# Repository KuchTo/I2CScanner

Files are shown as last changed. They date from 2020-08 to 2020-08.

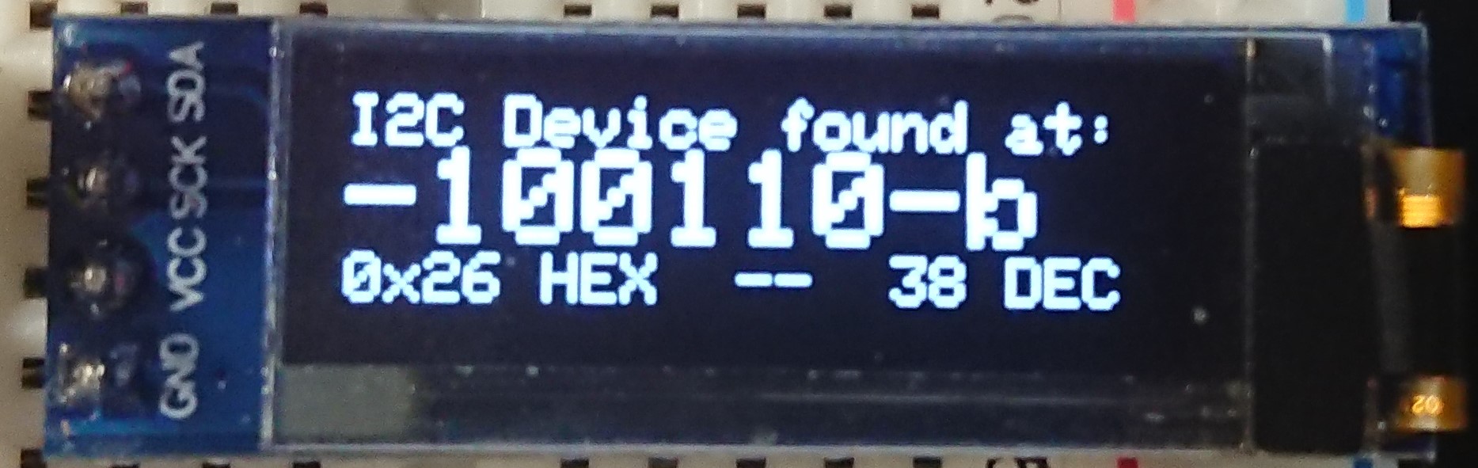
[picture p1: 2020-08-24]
I2C_Scanner_OLed.jpg

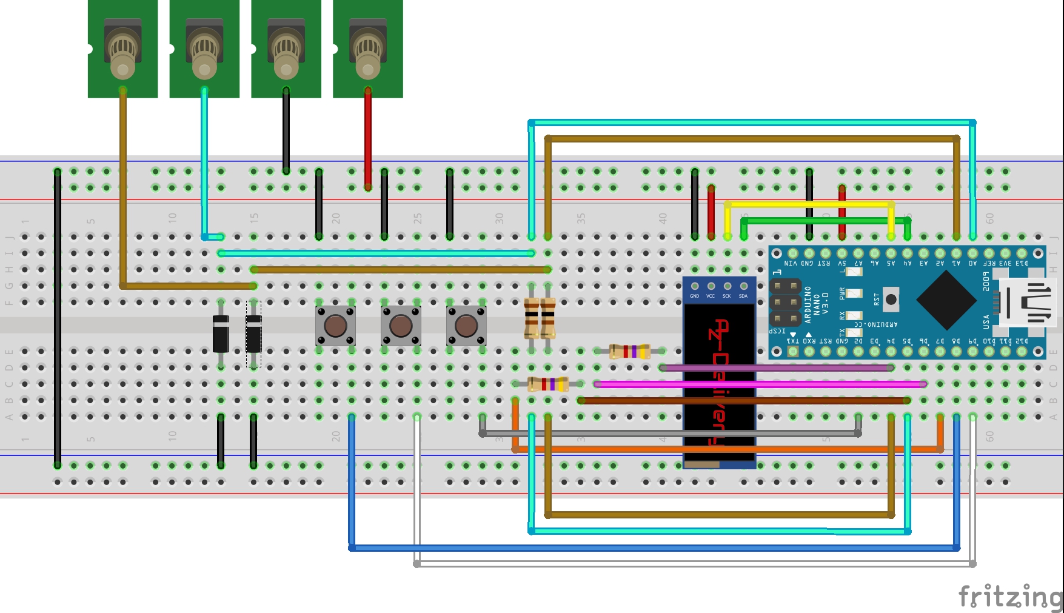
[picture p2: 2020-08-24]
Tool_I2CScanner_Teil_3_Steckplatine.jpg

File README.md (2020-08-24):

# I2CScanner
I2C Mini Scanner mit Frequenzgenerator und Logiktester 
Ein praktischer und kostengünstiger I2C Scanner - Reihe „Multitool“ Teil 1

Hallo und willkommen zu einer neuen Reihe rund um unseren Arduino! In dieser Reihe werden wir uns über insgesamt 3 Teile ein kleines kostengünstiges Elektronik Multitool bauen, das es ermöglicht IC2 Adressen aus einem angeschlossenen I2C Bauteil herauszulesen, (I2C Scanner), eine Rechteckspannung von 5 Volt in variabler Frequenz auszugeben und Spannung im Bereich von 0-5 Volt messen kann. In unserem ersten Teil werden wir einen I2C Scanner bauen. Doch warum schon wieder einen I2C - Scanner? Auslöser war, dass ich für ein anderes Projekt dringend eine Bestimmung der IC2 Adresse eines Bausteines brauchte, jedoch nicht so einfach ein Datenblatt für diesen Baustein im Internet fand. Also musste ein selbstgebauter I2C Scanner her. Auf nun folgenden Suche nach einem kostengünstigen Open Source IC2 Scanner waren die selbstaufgelegten Vorgaben für diesen Scanner die folgenden:

1)	Einfachheit: Kein Anschluss an einen PC benötigt. Für den Betrieb oder das Ablesen der I2C Adressen ist kein PC nötig.

2)	Minimalistisch: So kleine Bauteile wie möglich. (Unterbringung in einem kleinen Gehäuse)

3)	Kosteneffizienz: Keine unnötig teure Hardware. 

4)	Hardwareeffizienz: keine "brachliegenden" Ressourcen der Hardware wie WLAN, Bluetooth etc.

5)	Sparsam: Betrieb mit einem Akkupack möglich.
 
Ein System das alle die o.g. Kriterien für einen IC2 Scanner erfüllt, konnte ich nicht jedoch nicht finden. Also hieß es: Selbst machen und so ist dieser Blog entstanden. Kommen wir zunächst zu einigen Überlegungen:
Das erste Ziel, ohne PC auszukommen, kann nur mit einem eigenen Display erreicht werden, auf dem die Daten direkt angezeigt werden können.

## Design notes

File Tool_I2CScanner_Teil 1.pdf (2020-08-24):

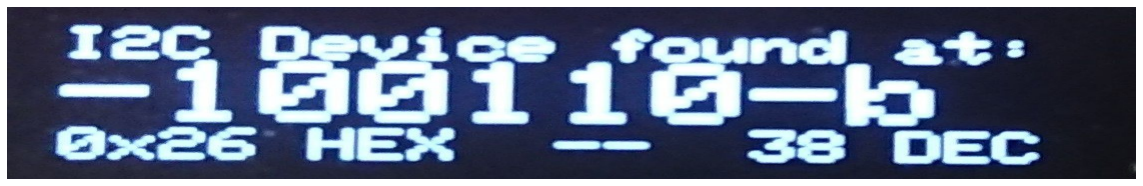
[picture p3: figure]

Ein praktischer und kostengünstiger I2C Scanner - Reihe „Multitool“ Teil 1

Hallo und willkommen zu einer neuen Reihe rund um unseren Arduino! In dieser Reihe werden wir uns über insgesamt 3 Teile ein kleines kostengünstiges Elektronik Multitool bauen, das es ermöglicht IC2 Adressen aus einem angeschlossenen I2C Bauteil herauszulesen, (I2C Scanner), eine Rechteckspannung von 5 Volt in variabler Frequenz auszugeben und Spannung im Bereich von 0-5 Volt messen kann. In unserem ersten Teil werden wir einen I2C Scanner bauen. Doch warum schon wieder einen I2C - Scanner? Auslöser war, dass ich für ein anderes Projekt dringend eine Bestimmung der IC2 Adresse eines Bausteines brauchte, jedoch nicht so einfach ein Datenblatt für diesen Baustein im Internet fand. Also musste ein selbstgebauter I2C Scanner her. Auf nun folgenden Suche nach einem kostengünstigen Open Source IC2 Scanner waren die selbstaufgelegten Vorgaben für diesen Scanner die folgenden:

1) Einfachheit: Kein Anschluss an einen PC benötigt. Für den Betrieb oder das Ablesen der I2C Adressen ist kein PC nötig.
2) Minimalistisch: So kleine Bauteile wie möglich. (Unterbringung in einem kleinen Gehäuse)
3) Kosteneffizienz: Keine unnötig teure Hardware.
4) Hardwareeffizienz: keine "brachliegenden" Ressourcen der Hardware wie WLAN, Bluetooth etc.
5) Sparsam: Betrieb mit einem Akkupack möglich.

Ein System das alle die o.g. Kriterien für einen IC2 Scanner erfüllt, konnte ich nicht jedoch nicht finden. Also hieß es: Selbst machen und so ist dieser Blog entstanden. Kommen wir zunächst zu einigen Überlegungen:
Das erste Ziel, ohne PC auszukommen, kann nur mit einem eigenen Display erreicht werden, auf dem die Daten direkt angezeigt werden können. Durch die Vorgabe eines minimalistischen Designs, auf dem nur so wenig wie möglich Platz zur Verfügung steht, blieb nach Sondierung der Displays auf der AZ-Delivery Seite nur das O-Led 128x64 Pixel in der engeren Auswahl. Dieses Display benötigt aber seinerseits schon einen I2C Bus um zu funktionieren. Was nun? Prozessoren mit 2 parallelen I2C Bussen "on Board" wie sie der ESP32 haben, fielen aber aufgrund der überzogenen Hardware (Bluetooth, WLAN, großer Speicher) für dieses Projekt durch. Ebenso aus gleichem Grunde der ESP8266 (Kosteneffizienz und Hardwareeffizienz).Blieb also nur der Arduino Nano für das Projekt übrig, den wir mit einem kleinen "Trick" auch nutzen können: Wir emulieren per Software einen weiteren I2C Port, der für das Scannen benutzt wird (Im folgenden Software I2C genannt).

Der Hardware I2C Bus wird für die Ansteuerung des O-Led Displays genutzt. Glücklicherweise gibt es bereits eine fertige Bibliothek um einen I2C Bus in Software zu emulieren. Diese heißt „Soft Wire“ und ist von Steve Marple.
Die Bibliothek kann von hier heruntergeladen werden: https://github.com/stevemarple/SoftWire
Weitere Informationen zu dieser Bibliothek finden sich auch auf der Seite https://www.arduinolibraries.info/libraries/soft-wire
Bevor also mit unserem heutigen Projekt begonnen werden kann, muss erst diese Bibliothek in bekannter Weise installiert werden. Für den I2C Scanner aus dem heutigen Blog benötigen Sie darüber hinaus noch folgende Teile aus dem Shop:
Anzahl | Bezeichnung | Anmerkung

### 1 Arduino Nano

1 0,91 Zoll OLED I2C Display 128 x 32 Pixel
2 4,7 KOhm Widerstände

Danach kann die Hardware gemäß folgender Fritzing-Zeichnung aufgebaut werden:

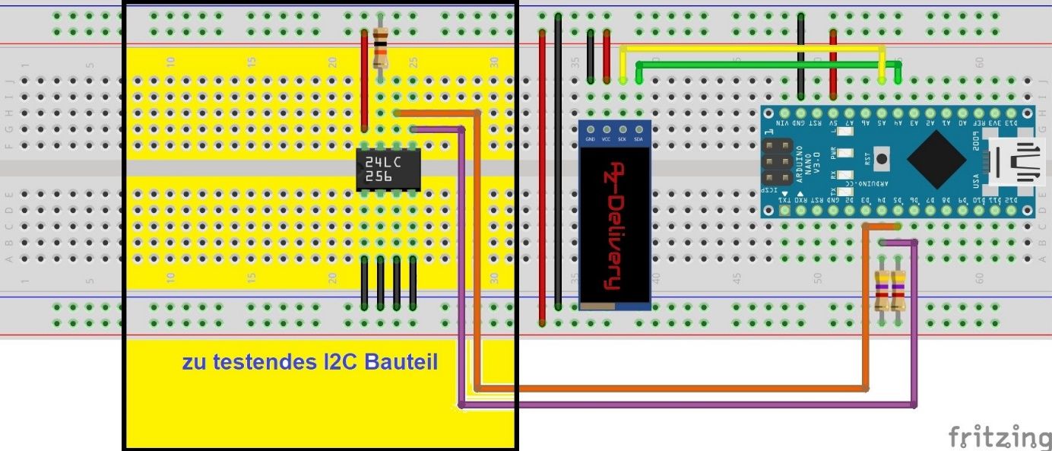
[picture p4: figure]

Beachten Sie die 4,5 K-Ohm Pullup-Widerstände für die Software I2C Schnittstelle. Diese werden für die Funktion benötigt. Aufgebaut auf einem Breadboard und in Betrieb sieht das ganze nun so aus:

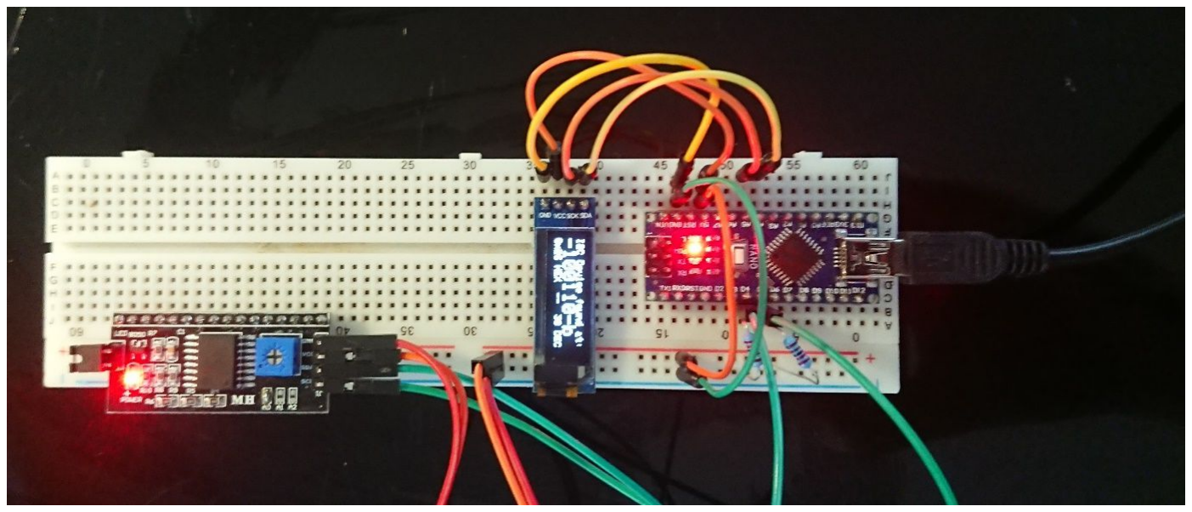
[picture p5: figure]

Nach dem Aufbau kann folgender Code hochgeladen werden:

// Tobias Kuch 2020 GPL 3.0 tobias.kuch@googlemail.com
// https://github.com/kuchto

/*
Dieser kurze Sketch durchsucht den I2C-Bus nach Geräten. Wenn ein Gerät gefunden wird, wird es auf einem 128x64 OLed Display
mit seiner Adresse in den Formaten Binär, Hexadezimal und Dezimal angezeigt.
*/

#include <Wire.h>

#include <SoftWire.h>

#include <AsyncDelay.h>

#include "SSD1306Ascii.h"

#include "SSD1306AsciiWire.h"

#define oLed_I2C_ADDRESS 0x3C #define SoftSDA 4

#define SoftSCL 5

const uint8_t firstAddr = 1; const uint8_t lastAddr = 0x7F;

SSD1306AsciiWire oled;
SoftWire sw(SoftSDA, SoftSCL);

//------------------------------------------------------------------------------

uint8_t I2C_Device_found_at_Address= 0;
uint16_t Round = 0;
bool AlreadyScan = false;

void setup()
{
Wire.begin();

Wire.setClock(400000L);
sw.setTimeout_ms(200); // Set how long we are willing to wait for a device to respond oled.begin(&Adafruit128x32, oLed_I2C_ADDRESS);
oled.setFont(Adafruit5x7);
oled.clear();
oled.set1X();
oled.clear();
oled.setCursor(0, 0);
oled.print("Scanning I2C Bus..."); oled.setCursor(0, 1);
oled.print("Initital Scan.");
}
//------------------------------------------------------------------------------

bool scanI2C()
{
bool detected=false;
for (uint8_t addr = firstAddr; addr <= lastAddr; addr++)
{
delayMicroseconds(50);
uint8_t startResult = sw.llStart((addr << 1) + 1); // Signal a read
sw.stop();
if ((startResult==0) & (I2C_Device_found_at_Address != addr)) // New I2C Device found {
Round = 0;
detected=true;
I2C_Device_found_at_Address = addr; AlreadyScan = false;
oled.set1X();
oled.setCursor(0,0);
// oled.clear();
oled.print("I2C Device found at: "); oled.setCursor(0,1);
oled.set2X();
oled.setCursor(0,1);
oled.print("-");
oled.print(addr,BIN);
oled.print("-b ");
oled.set1X();
oled.setCursor(0,3);
oled.print("0x");
if(addr<16) oled.print("0"); oled.print(addr,HEX);
oled.print(" HEX -- ");
if(addr<10) oled.print("0"); oled.print(addr,DEC);
oled.print(" DEC ");
delay(100);
break;
} // Device Found END
} // Scan Round END

if (!detected)

{
I2C_Device_found_at_Address = 0; Round++;
}
return detected;
} // Function END

void loop()
{
if ((!scanI2C()) && (Round > 2)) {
if (!AlreadyScan)
{
AlreadyScan = true;
oled.clear();
oled.setCursor(0, 0);
oled.print("Scanning I2C Bus..."); }
Round = 0;
I2C_Device_found_at_Address = 0; }
delay(200);
}

Sobald nun ein I2C adressierbarer und funktionsfähiger Baustein an den Port 5 (SCL) und Port 4 (SDA) angeschlossen wird, wird dessen Adresse umgehend im O-Led Display in den verschiedenen Zahlensystemen Binär, Dezimal und Hexadezimal angezeigt. Ich wünsche Ihnen viel Spaß beim Bauen und beim Verwenden des I2CScanners. Alle Projekte und Informationen meiner Blogs finden Sie auch unter https://github.com/kuchto.

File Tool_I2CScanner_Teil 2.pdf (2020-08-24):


### Ein einfacher und kostengünstiger Frequenzgenerator -

### Aus der Reihe „Multitool“ Teil 2

Hallo und willkommen zum zweiten Teil unserer Reihe rund um unser "Mini Tool".

Heute spendieren wir unserem Mini Tool zusätzlich zu der Verbesserung der Verwendung des I2C Scanners eine weitere Funktion: Ein Frequenzgenerator mit einem festen Tastgrad von 0,5 (symmetrischer Puls), einstellbar in einem Frequenzbereich von ca. 200 Hz bis ca. 25 Khz. Die Amplitude beträgt 5 Volt, die Effektivspannung Uev ca. 2.5 Volt. Der Puls steht am Pin 8 des Arduinos gegen Masse (GND) des Arduino Nanos für eigene Anwendungen oder Tests zur Verfügung. Das Einstellen der Frequenz in dem o.g. Bereich an Pin 8 des Arduinos erfolgt durch ein 10 K-Ohm Drehpotentiometer, das an den Analog Eingang A0 des Arduinos angeschlossen ist. Das Umschalten zwischen dem Modus "I2C Busscanner" und "Frequenzgenerator" und zurück, erfolgt durch Drücken des Tasters T1.Als weiteres

"Bonbon" im heutigen Teil erfolgt eine Verbesserung der Funktion des IC2 Scanners.

Beim Anschließen an einen I2C Prüfling muss nun NICHT mehr auf den korrekten Anschluss von den Datenleitungen SDA und SCL geachtet werden. Die Adressermittlung erfolgt jetzt unabhängig der Datenleitungsbeschaltung und wird, wie gewohnt, direkt im Display in den Formaten Binär, Dezimal und Hexadezimal

angezeigt.

### Um die neuen Funktionen implementieren zu können, benötigen wir folgende leicht erweiterteHardware:

Anzahl | Bezeichnung | Anmerkung

### 1 Arduino Nano

1 0,91 Zoll OLED I2C Display 128 x 32 Pixel
2 4,7 KOhm Widerstände
1 10-KOhm Präzisions –Drehpotentiometer

### 1 Taster

### Danach kann die Hardware gemäß folgender Fritzing-Zeichnung Schaltung wie folgt erweitert werden:

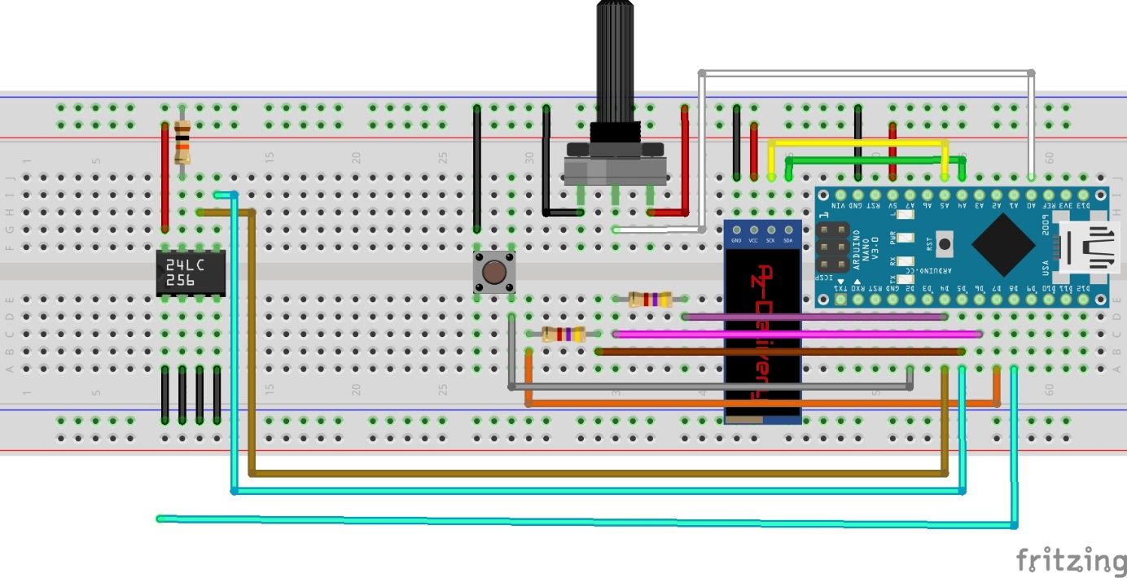
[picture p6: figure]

### Bitte beachten Sie beim Zusammenbau die etwas geänderte Schaltung der beiden

Pullup Widerstände. Diese sind nun nicht mehr direkt an Vcc (5 Volt) angeschlossen, sondern werden ihrerseits auch wieder durch Ports gesteuert. Warum dies Sinn macht, erfahren Sie im nächsten Teil dieser Reihe.

### Bevor es nun an das Hochladen des Codes geht, stellen Sie bitte sicher, dass bereits die Bibliothek „Soft Wire“ von Steve Marple in Ihrer IDE installiert ist. Die Bibliothek kann andernfalls von hier heruntergeladen werden. Weitere Informationen zu dieser

Bibliothek finden sie auch auf dieser Seite.

### Nun kann folgender Code auf den Arduino Nano geladen werden:

// Tobias Kuch 2020 GPL 3.0 tobias.kuch@googlemail.com
// https://github.com/kuchto

/*
Dieser kurze Sketch durchsucht den I2C-Bus nach Geräten. Wenn ein Gerät gefunden wird, wird es auf einem 128x64 OLed Display
mit seiner Adresse in den Formaten Binär, Hexadezimal und Dezimal angezeigt.
*/

#include <Wire.h>

#include <SoftWire.h>

#include <AsyncDelay.h>

#include "SSD1306Ascii.h"

#include "SSD1306AsciiWire.h"

#define oLed_I2C_ADDRESS 0x3C #define SoftI2CA 4

#define SoftI2CB 5

#define POTAConfig 6

#define POTBConfig 7

#define ModeSwitch 2 // Pin Modus Taster #define SQAREWaveOutputPin 8

#define POTENTIOMETER A0

const uint8_t firstAddr = 1; const uint8_t lastAddr = 0x7F;

SSD1306AsciiWire oled;
SoftWire sw(SoftI2CA, SoftI2CB);
SoftWire sw_rev(SoftI2CB, SoftI2CA);

//------------------------------------------------------------------------------

uint8_t I2C_Device_found_at_Address= 0;
uint16_t Round = 0;
bool AlreadyScan = false;
bool Alreadypressed = false;
bool Modeswitched = false;

byte SelectedMode = 0;
int oldvaluea = 0;

ISR(TIMER1_COMPA_vect){ //Timer1 interrupt. Schaltet Pin 8 um.
// Weitere Infos auf: https://www.mikrocontroller.net/articles/AVR-Tutorial:_Timer digitalWrite(SQAREWaveOutputPin,!(digitalRead(SQAREWaveOutputPin)));// Aufruffrequenz maximal: 2.604 Khz
//Frequenz an Pin 8(Hz) = (Arduino clock speed 16,000,000Hz) / (prescaler * (compare match register + 1)) / 2
}

void setup()
{
pinMode(ModeSwitch,INPUT_PULLUP); pinMode(SQAREWaveOutputPin, OUTPUT); pinMode(SoftI2CA, OUTPUT); pinMode(SoftI2CB, OUTPUT); pinMode(POTAConfig, OUTPUT); pinMode(POTBConfig, OUTPUT); digitalWrite (POTAConfig, HIGH); digitalWrite (POTBConfig, HIGH);
Serial.begin(9600);
cli(); | //stoppe alle Interrupts
TCCR1A = 0; | // set entire TCCR1A register to 0 TCCR - Timer/Counter Control
Register
TCCR1B = 0; | // Setze Timer/Counter Control Register TCCR1B auf 0
TCCR1B |= (1 << WGM12); | // Schalte Clear Timer on Compare (CTC) Modus ein
// TCCR1B |= (1 << CS12) | (1 << CS10); // Setze CS10 und CS12 Bit auf 1 für den 1024 Prescaler.
Maximalfrequenz: 7.812 Khz

TCCR1B |= (1 << CS12); | // Setze CS12 Bit auf 1 für den 256 Prescaler.
TCNT1 = 0; | // Initialisiere Zähler/Zeitgeber Register Wert auf 0
OCR1A = 130;// Aufruffrequenz Timer 1 241 Hz * 2
TIMSK1 |= (1 << OCIE1A); // Erlaube Timer compare interrupt TIMSK - Timer/Counter Interrupt Mask Register
sei();//allow interrupts
Wire.begin();
Wire.setClock(400000L);
sw.setTimeout_ms(200); // Set how long we are willing to wait for a device to respond sw_rev.setTimeout_ms(200); // Set how long we are willing to wait for a device to respond oled.begin(&Adafruit128x32, oLed_I2C_ADDRESS);
oled.setFont(Adafruit5x7);
oled.clear();
oled.set1X();
oled.clear();
oled.setCursor(0, 0);
oled.print("Scanning I2C Bus..."); oled.setCursor(0, 1);
oled.print("Initital Scan.");
}
//------------------------------------------------------------------------------

bool scanI2C()
{
bool detected=false;
for (uint8_t addr = firstAddr; addr <= lastAddr; addr++)
{
delayMicroseconds(50);
uint8_t startResult = sw.llStart((addr << 1) + 1); // Signal a read
sw.stop();
if ((startResult==0) & (I2C_Device_found_at_Address != addr)) // New I2C Device found {
Round = 0;
detected=true;
I2C_Device_found_at_Address = addr; AlreadyScan = false;
oled.set1X();
oled.setCursor(0,0);
// oled.clear();
oled.print("I2C Device found at: "); oled.setCursor(0,1);
oled.set2X();
oled.setCursor(0,1);
oled.print("-");
oled.print(addr,BIN);
oled.print("-b ");
oled.set1X();
oled.setCursor(0,3);
oled.print("0x");
if(addr<16) oled.print("0"); oled.print(addr,HEX);
oled.print(" HEX -- ");
if(addr<10) oled.print("0");

oled.print(addr,DEC);
oled.print(" DEC ");
delay(50);
break;
} // Device Found END
} // Scan Round END

if (!detected)
{
I2C_Device_found_at_Address = 0; Round++;
}
return detected;
} // Function END

bool scanI2C_rev()
{
bool detected=false;
for (uint8_t addr = firstAddr; addr <= lastAddr; addr++)
{
delayMicroseconds(50);
uint8_t startResult = sw_rev.llStart((addr << 1) + 1); // Signal a read
sw_rev.stop();
if ((startResult==0) & (I2C_Device_found_at_Address != addr)) // New I2C Device found {
Round = 0;
detected=true;
I2C_Device_found_at_Address = addr; AlreadyScan = false;
oled.set1X();
oled.setCursor(0,0);
// oled.clear();
oled.print("I2C Device found at: "); oled.setCursor(0,1);
oled.set2X();
oled.setCursor(0,1);
oled.print("-");
oled.print(addr,BIN);
oled.print("-b ");
oled.set1X();
oled.setCursor(0,3);
oled.print("0x");
if(addr<16) oled.print("0"); oled.print(addr,HEX);
oled.print(" HEX -- ");
if(addr<10) oled.print("0"); oled.print(addr,DEC);
oled.print(" DEC ");
delay(50);
break;
} // Device Found END
} // Scan Round END

if (!detected)
{
I2C_Device_found_at_Address = 0; Round++;
}
return detected;
} // Function END

void CheckMode()
{
bool PinStatus = digitalRead(ModeSwitch); if ((PinStatus == LOW) && !(Alreadypressed)) {
SelectedMode++;
if (SelectedMode > 1) { SelectedMode = 0; } Serial.print("Mode changed to: "); Serial.println(SelectedMode);
delay(50);
Alreadypressed = true;
Modeswitched = true;
} else if ((PinStatus == HIGH) && (Alreadypressed)) {
Alreadypressed = false;
}
}

void loop()
{
CheckMode();
if (SelectedMode == 0)
{
if (Modeswitched)
{
oled.clear();
}
Modeswitched = false;
if ((!scanI2C()) && (Round > 2)) {
if (!AlreadyScan)
{
AlreadyScan = true;
oled.clear();
oled.setCursor(0, 0);
oled.print("Scanning I2C Bus..."); }
Round = 0;
I2C_Device_found_at_Address = 0; }
if ((!scanI2C_rev()) && (Round > 2)) {
if (!AlreadyScan)
{
AlreadyScan = true;

oled.clear();
oled.setCursor(0, 0);
oled.print("Scanning I2C Bus..."); }
Round = 0;
I2C_Device_found_at_Address = 0; }
delay(50);
}

if (SelectedMode == 1)
{
if (Modeswitched)
{
oled.clear();
oled.setCursor(0, 0);
oled.print("Square Wave Generator"); }
Modeswitched = false;
int Gb = analogRead(POTENTIOMETER); byte valuea = Gb; // map(Gb,0,1023,0,300); if (valuea != oldvaluea)
{
oldvaluea = valuea ;
cli();//stop interrupts
OCR1A = valuea;
if ( TCNT1 > OCR1A )
{
TCNT1 = OCR1A -1;//initialize counter value to 0 }
sei();//allow interrupts
}
}
// END MainLoop
}

Sobald nun ein I2C adressierbarer und funktionsfähiger Baustein beliebig mit seinen Bus Ports an den Port 5 und Port 4 angeschlossen wird, und das Mini Tool im Modus „I2C Scanner“ betrieben wird, wird dessen Adresse umgehend im O-Led Display angezeigt. Der Frequenzgenerator kann für beliebige eigene Anwendungen genutzt werden, Ich wünsche Ihnen viel Spaß beim Bauen und beim Verwenden des kleinen Tools. Alle Projekte und Informationen meiner Blogs finden Sie, wie immer, auch unter

https://github.com/kuchto.

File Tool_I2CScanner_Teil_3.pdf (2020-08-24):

### Ein Voltmeter für die Digitaltechnik (0-5 Volt) – Aus der Reihe „Multitool“ Teil 3

### Willkommen zum dritten und letzten Teil der Reihe „Mini Multitool“ in der die Funktion des Tools um ein 2-Kanal Voltmeter mit einem Messbereich von 0-5 Volt erweitert wird und der noch eingeschränkte Komfort in der Bedienung sowie der Funktionalität des

im zweiten Teil der Reihe eingeführten Rechteck Frequenzgenerators verbessert wird.

Das generierte Frequenzsignal wird nun nicht mehr über einen separaten Pin ausgegeben, sondern kann bei einem Modus Wechsel mit Hilfe der “Mode-Taste“ direkt an den für den I2C Scanner genutzten Pins 4 und 5 abgegriffen werden. Dabei ist das Ausgangssignal an Pin 4 nicht invertiert und an Pin 5 invertiert. Das Potential

zwischen Pin 4 und Pin 5 beträgt im Frequenzgenerator Modus somit konstant 5 Volt.

Die Ausgänge der Pins 4 und 5 wurden mithilfe zweier Widerstände von je 100 Ohm in Reihe und zwei Zener-Dioden mit je 5,1 Volt Durchbruchsspannung gegen kurzzeitige und geringe Überlastung resistenter gemacht. Das Potentiometer zur Frequenz Einstellung ist zugunsten von 2 Tastern zur genaueren und präziseren Einstellung ersetzt worden. Die ausgegebene Frequenz auf der jeweilig eingestellten Stufe (1- 254) im Bereich von 122 Hz bis 15,625 KHz wird nun auf dem O-Led Display angezeigt. Die Genauigkeit der in der O-Led angezeigten Frequenz hängt dabei von dem Systemquarz ab. In dem hier vorgestellten Code wird von einer genauen Systemquarzfrequenz von 16 MHz. ausgegangen. Sollte Ihr Quarz von dieser

Systemquarzfrequenz | abweichen, | so | tragen | sie | bitte | Ihre | ermittelte

### Systemquarzfrequenz in Hz in der Codezeile

### #define CrystalFreq 16000000 // Systemquarzfrequenz des Arduinos

ein bzw. korrigieren diese nach oben oder unten. Für die Genauigkeit des Voltmeters ist zum einen die Ermittlung der genutzten Analog-Digital Referenzspannung wichtig als auch die Genauigkeit des AD Wandlers. Da wir auf den internen AD Wandler des Arduinos nicht direkt Einfluss nehmen können, bleibt nur die Kalibration der Referenzspannung. Bitte messen Sie dazu mit einem genügend genauen Voltmeter die Spannung an dem „URef“ Pins des Arduinos gegen Masse und tragen die gemessene Spannung in die Codezeile
#define UReference 5.0 | // Spannungsreferenz für den Analogwandler

### ein bzw. korrigieren diese. Im Normalfall sollte diese Spannung im Bereich von 4 bis

maximal 5 Volt liegen.

Um die neuen Funktionen und Schutzmaßnahmen implementieren zu können,

### benötigen wir erneut eine leicht abgeänderte Hardware und damit eine veränderte Teileliste:

Anzahl | Bezeichnung | Anmerkung

### 1 Arduino Nano

1 0,91 Zoll OLED I2C Display 128 x 32 Pixel
2 4,7 KOhm Widerstände
2 100 Ohm Widerstände

### 3 Taster 2 Zener-Dioden 5,1 Volt

### Danach kann die Hardware gemäß folgender Fritzing-Zeichnung Schaltung wie folgt erweitert werden:

| Anschluss Ports und 5 Volt Potential

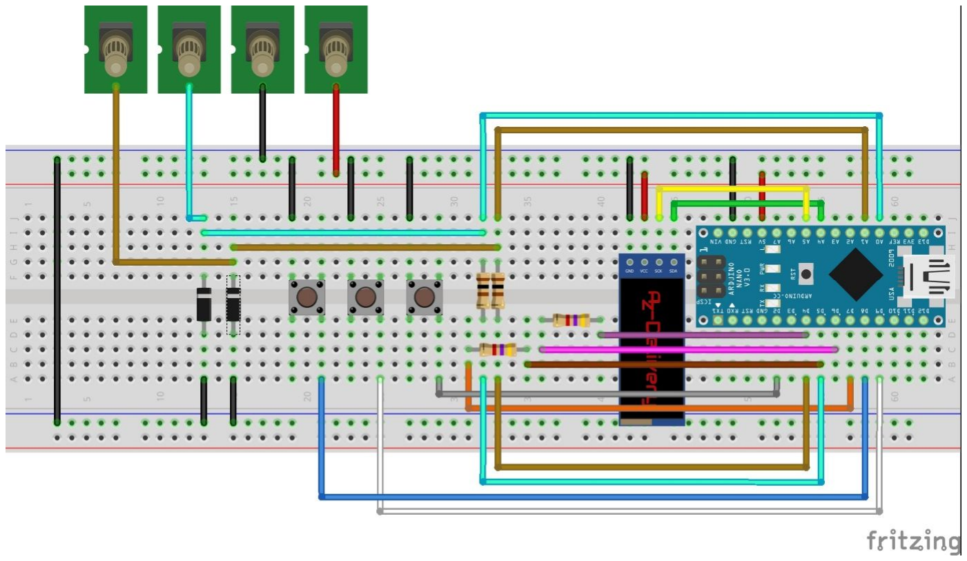
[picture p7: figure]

An dieser Stelle möchte ich, wie versprochen, auf die im letzten Teil angesprochene geänderte Schaltung der beiden Pullup-Widerstände zu sprechen kommen. Durch den Anschluss an Ports statt an festen Potentialen wird der angeschlossene Widerstand „programmierbar“. d.h. durch gezieltes setzen der Zustände der Anschluss Ports der beiden Widerstände können diese wahlweise zu Pullup-Pulldown oder zu schaltungstechnisch neutralen Widerständen geschaltet werden. Dies nutze ich bei z.B beim Modus „I2C -Scanner“ (Teil 1) aus, indem die beiden 4,7 K Ohm Widerstände zu Pullup Widerständen werden, im Frequenzgenerator Modus (Teil 2) werden Sie dagegen deaktiviert. Im Voltmetermodus (Teil 3) werden sie zu Pulldown-

Widerständen um ein definiertes Potential bei nicht Beschaltung der Port zu haben. Dies verhindert fehlerhafte Spanungsmessungen über den empfindlichen AD Wandler.

### Bevor es nun an das Hochladen des Codes geht, stellen Sie bitte auch in diesem Teil sicher, dass bereits die Bibliothek „Soft Wire“ von Steve Marple in Ihrer IDE installiert ist. Die Bibliothek kann andernfalls von hier heruntergeladen werden. Weitere

Informationen zu dieser Bibliothek finden sie auch auf dieser Seite.

### Aufgebaut auf meinem Breadboard sieht das Multitool nun wie folgt aus:

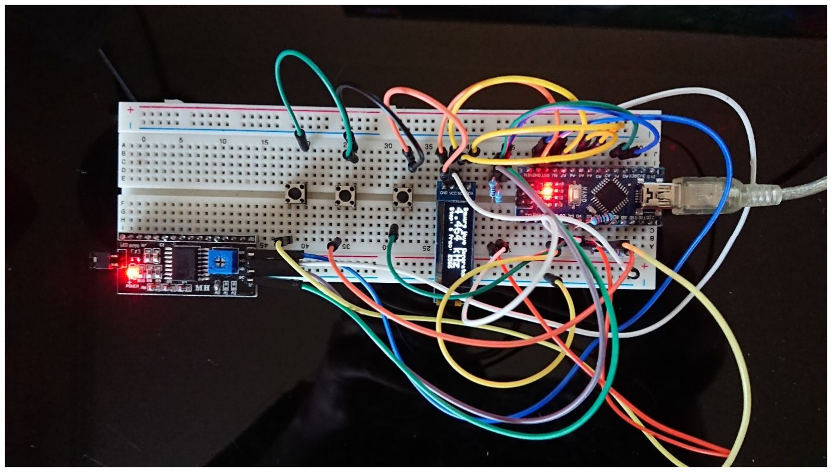
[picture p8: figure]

### Ein Hinweis zur Bedienung:

### Bevor ein Modus umgeschaltet werden kann, ist der Prüfling oder die Last von den Ausgangspins zu trennen. Es darf niemals während eines laufenden Tests der Modus umgeschaltet werden, da es ansonsten zu Fehlfunktionen oder zur

Beschädigung des Prüflings kommen kann.

### Nun kann folgender Code auf den Arduino Nano geladen werden:

// Tobias Kuch 2020 GPL 3.0 tobias.kuch@googlemail.com
// https://github.com/kuchto

#include <Wire.h>

#include <SoftWire.h>

//#include <AsyncDelay.h>
#include "SSD1306Ascii.h"

#include "SSD1306AsciiWire.h"

#define oLed_I2C_ADDRESS 0x3C

#define VSensor0 A0

#define VSensor1 A1

#define UniIOA 4

#define UniIOB 5

#define POTAConfig 6

#define POTBConfig 7

#define UpSwitch 8 | // Pin Up Taster

#define DownSwitch 9 | // Pin Down Taster

#define ModeSwitch 2 | // Pin Modus Taster

#define Prescaler 256 | // Mögliche Werte: 1,8,64,256,1024

#define CrystalFreq 16000000 // Quarzgeschwindikeit des Arduinos: Standard: 16 mhz #define UReference 4.5 // Spannungsreferenz für den Analogwandler (hier: 4.5 Volt) #define ADResolution 1023

#define interval1 500 // Zeitraum in ms zwischen 2 analog Messungen der Spannung an A0 und A1

const uint8_t firstAddr = 1;
const uint8_t lastAddr = 0x7F;

SSD1306AsciiWire oled;
SoftWire sw(UniIOA, UniIOB);
SoftWire sw_rev(UniIOB, UniIOA);

//------------------------------------------------------------------------------

uint8_t I2C_Device_found_at_Address = 0;
uint16_t Round = 0;
uint16_t IntFreqStepOld = 0;

bool AlreadyScan = false;
bool Alreadypressed1 = false; bool Alreadypressed2 = false; bool Alreadypressed3 = false; bool Modeswitched = false;

byte SelectedMode = 0;

unsigned int IntFreqStep = 1;

unsigned long previousMillis1 = 0; unsigned long Frequency = 0;

float VoltageMultiplicator = 0;

ISR(TIMER1_COMPA_vect) { //Timer1 interrupt.
// Weitere Infos auf: https://www.mikrocontroller.net/articles/AVR-Tutorial:_Timer digitalWrite(UniIOA, !(digitalRead(UniIOA)));
digitalWrite(UniIOB, !(digitalRead(UniIOB)));

}

void setup()
{
pinMode(ModeSwitch, INPUT_PULLUP); pinMode(UpSwitch, INPUT_PULLUP); pinMode(DownSwitch, INPUT_PULLUP); pinMode(UniIOA, OUTPUT);
pinMode(UniIOB, OUTPUT);
pinMode(POTAConfig, OUTPUT); pinMode(POTBConfig, OUTPUT); digitalWrite (POTAConfig, HIGH);
digitalWrite (POTBConfig, HIGH);
cli(); | // stoppe alle Interrupts
TCCR1A = 0; | // set entire TCCR1A register to 0 TCCR - Timer/Counter Control
Register
TCCR1B = 0; | // Setze Timer/Counter Control Register TCCR1B auf 0
TCCR1B |= (1 << WGM12); | // Schalte Clear Timer on Compare (CTC) Modus ein
if (Prescaler == 0)
{
TCCR1B |= (1 << CS10); | // Setze Prescaler auf 0.
}
if (Prescaler == 8)
{
TCCR1B |= (1 << CS11); | // Setze CS11 Bit auf 1 für den 8 Prescaler.
}
if (Prescaler == 64)
{
TCCR1B |= (1 << CS11) | (1 << CS10); // Setze CS10 und CS11 Bit auf 1 für den 64 Prescaler.
}
if (Prescaler == 256)
{
TCCR1B |= (1 << CS12); | // Setze CS12 Bit auf 1 für den 256 Prescaler.
}
if (Prescaler == 1024)
{
TCCR1B |= (1 << CS12) | (1 << CS10); // Setze CS10 und CS12 Bit auf 1 für den 1024 Prescaler.
}
TCNT1 = 0; | // Initialisiere Zähler/Zeitgeber Register Wert auf 0
OCR1A = 130; | // Aufruffrequenz Timer 1 241 Hz * 2
TIMSK1 &= (0 << OCIE1A); | // Sperre Timer Compare interrupt TIMSK - Timer/Counter
Interrupt Mask Register
sei(); | // erlaube interrupts
VoltageMultiplicator = float(UReference)/float(ADResolution);
Wire.begin();
Wire.setClock(400000L);
sw.setTimeout_ms(200); | // Software I2C Bus Objekt 1 TimeOut
sw_rev.setTimeout_ms(200); | // Software I2C Bus Objekt 2 TimeOut
oled.begin(&Adafruit128x32, oLed_I2C_ADDRESS); oled.setFont(Adafruit5x7);
oled.clear();
oled.set1X();
oled.clear();

oled.setCursor(0, 0);
oled.print("Scanning I2C Bus..."); oled.setCursor(0, 1);
oled.print("Initital Scan.");
}
//------------------------------------------------------------------------------

bool scanI2C()
{
bool detected = false;
for (uint8_t addr = firstAddr; addr <= lastAddr; addr++)
{
uint8_t startResult = sw.llStart((addr << 1) + 1); // Signal a read
sw.stop();
if ((startResult == 0) & (I2C_Device_found_at_Address != addr)) // New I2C Device found {
Round = 0;
detected = true;
I2C_Device_found_at_Address = addr; AlreadyScan = false;
oled.set1X();
oled.setCursor(0, 0);
oled.print("I2C Device found at: "); oled.setCursor(0, 1);
oled.set2X();
oled.setCursor(0, 1);
oled.print("-");
oled.print(addr, BIN);
oled.print("-b ");
oled.set1X();
oled.setCursor(0, 3);
oled.print("0x");
if (addr < 16) oled.print("0"); oled.print(addr, HEX);
oled.print(" HEX -- ");
if (addr < 10) oled.print("0"); oled.print(addr, DEC);
oled.print(" DEC ");
break;
} // Device Found END
} // Scan Round END
if (!detected)
{
I2C_Device_found_at_Address = 0; Round++;
}
return detected;
} // Function END

bool scanI2C_rev()
{
bool detected = false;
for (uint8_t addr = firstAddr; addr <= lastAddr; addr++)

{
uint8_t startResult = sw_rev.llStart((addr << 1) + 1); // Signal a read
sw_rev.stop();
if ((startResult == 0) & (I2C_Device_found_at_Address != addr)) // New I2C Device found {
Round = 0;
detected = true;
I2C_Device_found_at_Address = addr; AlreadyScan = false;
oled.set1X();
oled.setCursor(0, 0);
oled.print("I2C Device found at: "); oled.setCursor(0, 1);
oled.set2X();
oled.setCursor(0, 1);
oled.print("-");
oled.print(addr, BIN);
oled.print("-b ");
oled.set1X();
oled.setCursor(0, 3);
oled.print("0x");
if (addr < 16) oled.print("0"); oled.print(addr, HEX);
oled.print(" HEX -- ");
if (addr < 10) oled.print("0"); oled.print(addr, DEC);
oled.print(" DEC ");
break;
} // Device Found END
} // Scan Round END

if (!detected)
{
I2C_Device_found_at_Address = 0; Round++;
}
return detected;
} // Function END

void CheckMode()
{
bool PinStatus1 = digitalRead(UpSwitch);
if ((PinStatus1 == LOW) && !(Alreadypressed1)) {
delay(200);
IntFreqStep = IntFreqStep + 1;
if (IntFreqStep > 254)
{
IntFreqStep = 254;
}
Alreadypressed1 = true;
} else if ((PinStatus1 == HIGH) && (Alreadypressed1)) {

Alreadypressed1 = false;
}

bool PinStatus2 = digitalRead(DownSwitch); if ((PinStatus2 == LOW) && !(Alreadypressed2)) {
delay(200);
IntFreqStep = IntFreqStep - 1;
if (IntFreqStep < 1)
{
IntFreqStep = 1;
}
Alreadypressed2 = true;
} else if ((PinStatus2 == HIGH) && (Alreadypressed2)) {
Alreadypressed2 = false;
}

bool PinStatus3 = digitalRead(ModeSwitch); if ((PinStatus3 == LOW) && !(Alreadypressed3)) {
delay(200);
SelectedMode++;
if (SelectedMode > 2) {
SelectedMode = 0;
}
Alreadypressed3 = true;
Modeswitched = true;
} else if ((PinStatus3 == HIGH) && (Alreadypressed3)) {
Alreadypressed3 = false;
}
}

void loop()
{
CheckMode();
if (SelectedMode == 0) // I2C Scanner Modus {
if (Modeswitched)
{
cli(); //disable interrupts
TIMSK1 &= (0 << OCIE1A); // Sperre Timer Compare interrupt TIMSK - Timer/Counter Interrupt Mask Register
sei(); //allow interrupts
pinMode(POTAConfig, OUTPUT);
pinMode(POTBConfig, OUTPUT); digitalWrite (POTAConfig, HIGH); digitalWrite (POTBConfig, HIGH); oled.clear();
oled.setCursor(0, 0);
oled.print("Scanning I2C Bus..."); }

Modeswitched = false;
if ((!scanI2C()) && (Round > 2)) {
if (!AlreadyScan)
{
AlreadyScan = true;
oled.clear();
oled.setCursor(0, 0);
oled.print("Scanning I2C Bus..."); }
Round = 0;
I2C_Device_found_at_Address = 0; }
}
CheckMode();
if (SelectedMode == 0) // I2C Scanner Modus {
if (Modeswitched)
{
cli(); //disable interrupts
TIMSK1 &= (0 << OCIE1A); // Sperre Timer Compare interrupt TIMSK - Timer/Counter Interrupt Mask Register
TCNT1 = 0; | // Lösche Counter Value
sei(); //allow interrupts
pinMode(POTAConfig, OUTPUT); pinMode(POTBConfig, OUTPUT); digitalWrite (POTAConfig, HIGH); digitalWrite (POTBConfig, HIGH); oled.clear();
oled.setCursor(0, 0);
oled.print("Scanning I2C Bus..."); }
Modeswitched = false;
if ((!scanI2C_rev()) && (Round > 2)) {
if (!AlreadyScan)
{
AlreadyScan = true;
oled.clear();
oled.setCursor(0, 0);
oled.print("Scanning I2C Bus..."); }
Round = 0;
I2C_Device_found_at_Address = 0; }
}
CheckMode();
if (SelectedMode == 1) // Square Wave Generator {
if (Modeswitched)
{

digitalWrite(POTAConfig, LOW);

digitalWrite(POTBConfig, LOW); pinMode(POTAConfig, INPUT); pinMode(POTBConfig, INPUT); pinMode(UniIOA, OUTPUT);
pinMode(UniIOB, OUTPUT);
digitalWrite(UniIOA, LOW); digitalWrite(UniIOB, HIGH);
cli(); //disable interrupts
TCNT1 = 0; | // Lösche Counter Value
TIMSK1 |= (1 << OCIE1A); // Erlaube Timer compare interrupt TIMSK - Timer/Counter Interrupt Mask Register
sei(); //allow interrupts
oled.clear();
oled.setCursor(0, 0);
oled.print("Square Wave Generator"); oled.set2X();
oled.setCursor(0, 1);
float Result = float(Frequency) / 1000; if (Result > 1)
{
oled.print(Result,3);
oled.print(" kHz ");
} else
{
oled.print(float(Frequency),2); oled.print(" Hz ");
}
oled.set1X();
oled.setCursor(0, 3);
oled.print("Step: ");
oled.print(IntFreqStep);
oled.print(" Prsc: ");
oled.println(Prescaler);
}
Modeswitched = false;

if (IntFreqStep != IntFreqStepOld) {
IntFreqStepOld = IntFreqStep; cli();//stop interrupts
OCR1A = IntFreqStep;
if ( TCNT1 >= OCR1A )
{
TCNT1 = OCR1A - 1; //initialize counter value to 0
}
sei();//allow interrupts
Frequency = (CrystalFreq / Prescaler) / (IntFreqStep + 1) / 2; oled.set2X();
oled.setCursor(0, 1);
double Result = float(Frequency) / 1000; Serial.println(Result);
if (Result > 1)
{

oled.print(Result,3);
oled.print(" kHz ");
} else
{
oled.print(Frequency);
oled.print(" Hz ");
}
oled.set1X();
oled.setCursor(0, 3);
oled.print("Step: ");
oled.print(IntFreqStep);
oled.print(" Prsc: ");
oled.println(Prescaler);
// oled.print(" ");
}
}
CheckMode();
if (SelectedMode == 2) // 2 Channel Voltmeter 0- 5 Volt 2 stellen genau. Vref ist mit 5 Volt angegeben.
{
if (Modeswitched)
{
cli(); //disable interrupts
TIMSK1 &= (0 << OCIE1A); // Verbiete Timer compare interrupt TIMSK - Timer/Counter Interrupt Mask Register
TCNT1 = 0; | // Lösche Counter Value
sei(); //allow interrupts
digitalWrite(POTAConfig, LOW); digitalWrite(POTBConfig, LOW); pinMode(POTAConfig, OUTPUT); pinMode(POTBConfig, OUTPUT); digitalWrite(UniIOB, LOW); digitalWrite(UniIOA, LOW); pinMode(UniIOB, INPUT);
pinMode(UniIOA, INPUT);
oled.clear();
oled.setCursor(0, 0);
oled.print("2 Ch. Voltage Sensor"); oled.setCursor(0, 1);
oled.print("Channel 1 Channel 2 "); }
Modeswitched = false;
if (millis() - previousMillis1 > interval1)
{
previousMillis1 = millis(); // aktuelle Zeit abspeichern oled.set2X();
int VS0 = analogRead(VSensor0); // read the input pin int VS1 = analogRead(VSensor1); // read the input pin float Voltage1 = float(VS0) * VoltageMultiplicator; float Voltage2 = float(VS1) * VoltageMultiplicator; oled.setCursor(0, 2);
oled.print(Voltage1,2);
oled.print("V");

oled.setCursor(66, 2);
oled.print(Voltage2,2);
oled.print("V");
oled.set1X();
}
}
// END MainLoop
}

Das Tool lässt sich durch den flexiblen Hardwareaufbau noch beliebig um weitere Funktionen erweitern, beispielsweise um einen Logiktester, der im TTL Bereich von 0-5 V den logischen Zustand der Ports 4 und 5auf dem Display anzeigt. Oder z.B. auch um eine sendende serielle Schnittstelle, die ständig Zufallszeichen mit einer variablen

Baudrate auf den Pins sendet.

Dank des speichersparenden und optimierten Codes verwendet der gesamte Sketch nur 11818 Bytes (38%) des Programmspeicherplatzes. Das Maximum des Arduino Nanos ist 30720 Bytes. Der globalen Variablen verwenden 757 Bytes (36%) des dynamischen Speichers, 1291 Bytes für lokale Variablen verbleiben für Ihre

Erweiterungen.

### Alle Projekte und Informationen meiner Blogs finden Sie, wie immer, auch unter

https://github.com/kuchto.
Ich wünsche Ihnen viel Spaß beim Bauen und beim Verwenden des kleinen Tools.

### Tobias Kuch

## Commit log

2020-08-24 Arduino Quelltext Dateien Sketches
2020-08-24 I2C Scanner Projektdokumenation Teil 1-3
2020-08-24 Schaltung I2C_Scanner Teil 1-3
    [Tool_I2CScanner_Teil_1.fzz, Tool_I2CScanner_Teil_2.fzz, Tool_I2CScanner_Teil_3.fzz]
